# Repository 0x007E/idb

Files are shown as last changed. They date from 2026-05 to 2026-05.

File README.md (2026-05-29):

  

# `IDB` - Inverter Development Board

The `IDB` is a board with an [CD40106](#additional-information) or any other 6-channel inverter that meets the pin requirements. The board itself can be driven from `5` to `15V`. The board offers the possibility to invert signals from buttons, switches or any other logic board.

| Experience  | Level |
|:---|:---:|
| Soldering | ?% |

# Downloads

| Type | File | Description |
|:---:|:---:|:---|
| Schematic | [pdf](https://github.com/0x007E/idb/releases/latest/download/schematic.pdf) / [cadlab](https://cadlab.io/project/30124/main/files) | Schematic files |
| Board | [pdf](https://github.com/0x007E/idb/releases/latest/download/pcb.pdf) / [cadlab](https://cadlab.io/project/30124/main/files) | Board file |
| Drill | [pdf](https://github.com/0x007E/idb/releases/latest/download/drill.pdf) | Drill file |
| BoM | [xlsx](https://github.com/0x007E/idb/releases/latest/download/bom.xlsx) / [html](https://github.com/0x007E/idb/releases/latest/download/bom.html) | Bill of Material as Excel/interactive HTML |
| PCB | [zip](https://github.com/0x007E/idb/releases/latest/download/kicad.zip) / [tar](https://github.com/0x007E/idb/releases/latest/download/kicad.tar.gz) | KiCAD/Gerber/BoM/Drill files |
| Mechanical | [zip](https://github.com/0x007E/idb/releases/latest/download/freecad.zip) / [tar](https://github.com/0x007E/idb/releases/latest/download/freecad.tar.gz) | FreeCAD/Housing and PCB (STEP/STL) files |

# Hardware

The pcb is created with `KiCAD`. All files are built with `github actions` so that they are ready for a production environment.

## PCB

The circuit board is populated on both sides (Top, Bottom). The best way for soldering the `SMD` components is within a vapor phase soldering system and for the `THT` components with a standard soldering system.

### Top Layer

Top Layer

### Bottom Layer

Bottom Layer

# Additional Information

| Type | Link | Description |
|:---:|:---:|:---|
| CD40106 | [pdf](https://www.ti.com/lit/ds/symlink/cd40106b.pdf) | CD40106B CMOS Hex Schmitt-Trigger Inverters |

---

R. GAECHTER

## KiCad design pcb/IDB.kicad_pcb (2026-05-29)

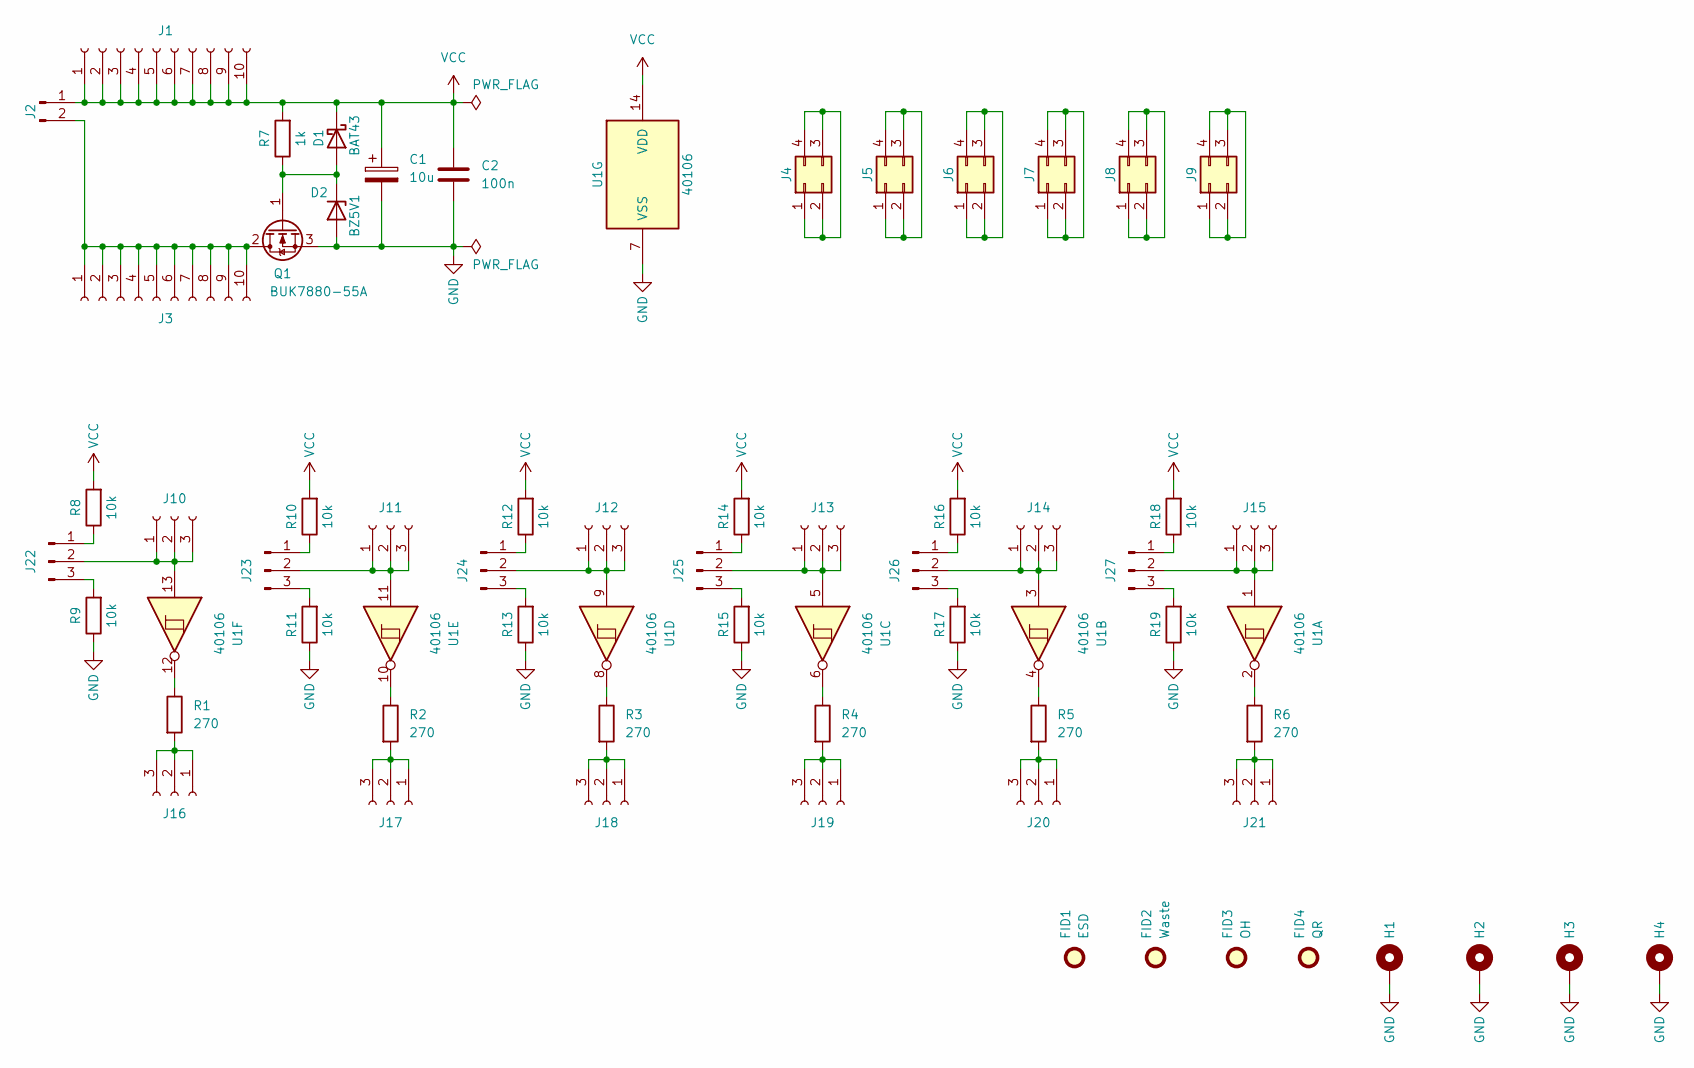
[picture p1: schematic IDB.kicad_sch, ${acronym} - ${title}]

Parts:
C1: 10u; CP_Radial_D6.3mm_P2.50mm
C2: 100n; C_1206_3216Metric
D1: BAT43; D_MiniMELF
D2: BZ5V1; D_MiniMELF
FID1: ESD; ESD-Logo_6.6x6mm_SilkScreen
FID2: Waste; WEEE-Logo_4.2x6mm_SilkScreen
FID3: OH; OSHW-Logo_5.7x6mm_SilkScreen
FID4: QR; QR_0x007e
H1, H2, H3, H4: MountingHole_Pad; MountingHole_3.2mm_M3_Pad
J1, J3: Conn_01x10_Socket; PinSocket_1x10_P2.54mm_Vertical; DigiKey 2057-RS1-10-G-ND
J2: Conn_01x02_Pin; PinHeader_1x02_P2.54mm_Vertical
J4, J5, J6, J7, J8, J9: Conn_02x02_Counter_Clockwise; PinSocket_2x02_P2.54mm_Vertical; DigiKey 2057-RS2-04-G-ND
J10, J11, J12, J13, J14, J15, J16, J17, J18, J19, J20, J21: Conn_01x03_Socket; PinSocket_1x03_P2.54mm_Vertical; DigiKey 2057-RS1-03-G-ND
J22, J23, J24, J25, J26, J27: Conn_01x03_Pin; PinHeader_1x03_P2.54mm_Vertical
Q1: BUK7880-55A; SOT-223-3_TabPin2
R1, R2, R3, R4, R5, R6: 270; R_1206_3216Metric
R7: 1k; R_1206_3216Metric
R8, R9, R10, R11, R12, R13, R14, R15, R16, R17, R18, R19: 10k; R_1206_3216Metric
U1: 40106; SOIC-14_3.9x8.7mm_P1.27mm; DigiKey 296-14081-1-ND

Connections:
GND: C1.2, C2.2, D2.2 (A), H1.1, H2.1, H3.1, H4.1, Q1.3 (S), R9.1, R11.1, R13.1, R15.1, R17.1, R19.1, U1.7 (VSS)
unnamed: D1.2 (A), D2.1 (K), Q1.1 (G), R7.1
unnamed: J2.2, J3.1, J3.2, J3.3, J3.4, J3.5, J3.6, J3.7, J3.8, J3.9, J3.10, Q1.2 (D)
unnamed: J4.1, J4.2, J4.3, J4.4
unnamed: J5.1, J5.2, J5.3, J5.4
unnamed: J6.1, J6.2, J6.3, J6.4
unnamed: J7.1, J7.2, J7.3, J7.4
unnamed: J8.1, J8.2, J8.3, J8.4
unnamed: J9.1, J9.2, J9.3, J9.4
unnamed: J10.1, J10.2, J10.3, J22.2, U1.13
unnamed: J11.1, J11.2, J11.3, J23.2, U1.11
unnamed: J12.1, J12.2, J12.3, J24.2, U1.9
unnamed: J13.1, J13.2, J13.3, J25.2, U1.5
unnamed: J14.1, J14.2, J14.3, J26.2, U1.3
unnamed: J15.1, J15.2, J15.3, J27.2, U1.1
unnamed: J16.1, J16.2, J16.3, R1.2
unnamed: J17.1, J17.2, J17.3, R2.2
unnamed: J18.1, J18.2, J18.3, R3.2
unnamed: J19.1, J19.2, J19.3, R4.2
unnamed: J20.1, J20.2, J20.3, R5.2
unnamed: J21.1, J21.2, J21.3, R6.2
unnamed: J22.1, R8.1
unnamed: J22.3, R9.2
unnamed: J23.1, R10.1
unnamed: J23.3, R11.2
unnamed: J24.1, R12.1
unnamed: J24.3, R13.2
unnamed: J25.1, R14.1
unnamed: J25.3, R15.2
unnamed: J26.1, R16.1
unnamed: J26.3, R17.2
unnamed: J27.1, R18.1
unnamed: J27.3, R19.2
unnamed: R1.1, U1.12
unnamed: R2.1, U1.10
unnamed: R3.1, U1.8
unnamed: R4.1, U1.6
unnamed: R5.1, U1.4
unnamed: R6.1, U1.2
VCC: C1.1, C2.1, D1.1 (K), J1.1, J1.2, J1.3, J1.4, J1.5, J1.6, J1.7, J1.8, J1.9, J1.10, J2.1, R7.2, R8.2, R10.2, R12.2, R14.2, R16.2, R18.2, U1.14 (VDD)

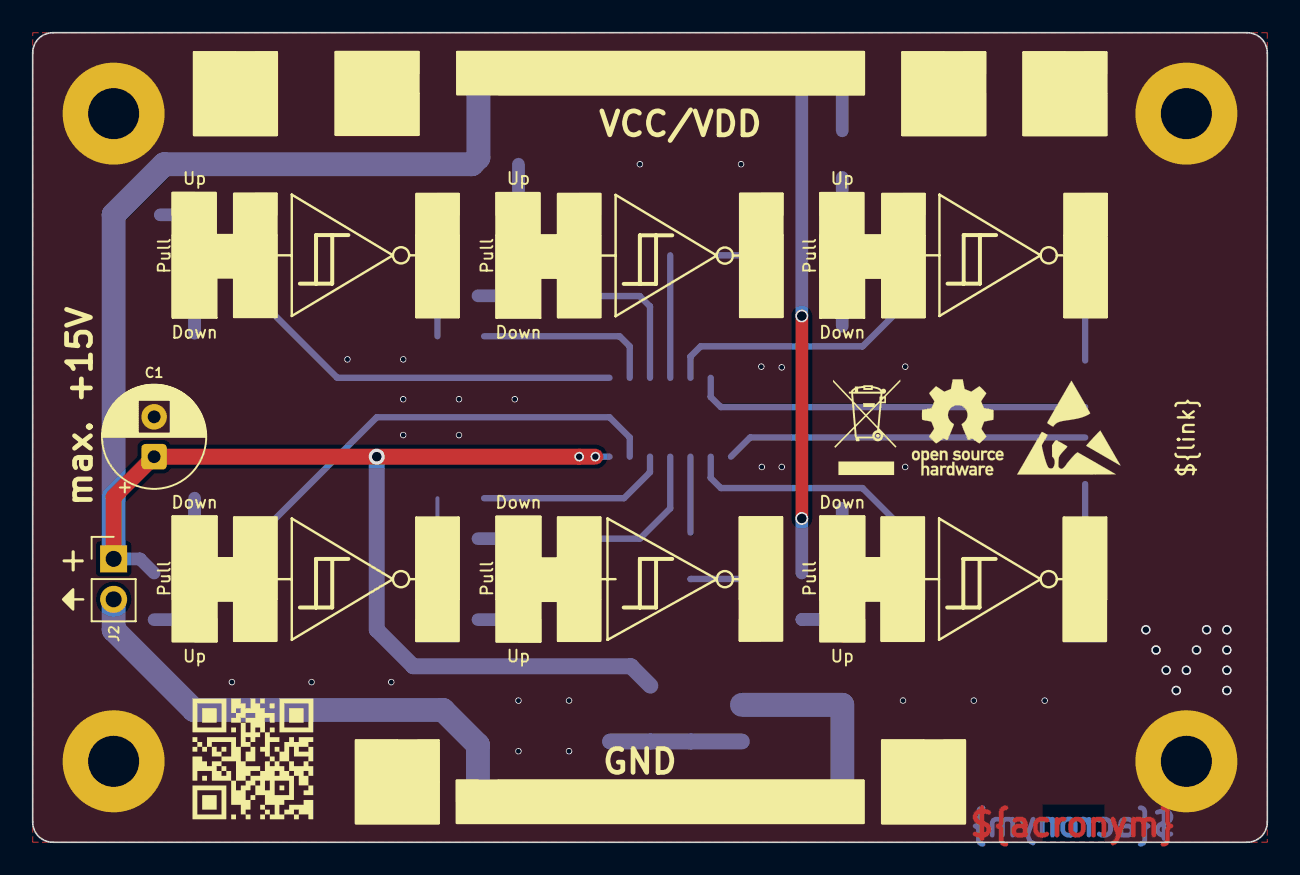
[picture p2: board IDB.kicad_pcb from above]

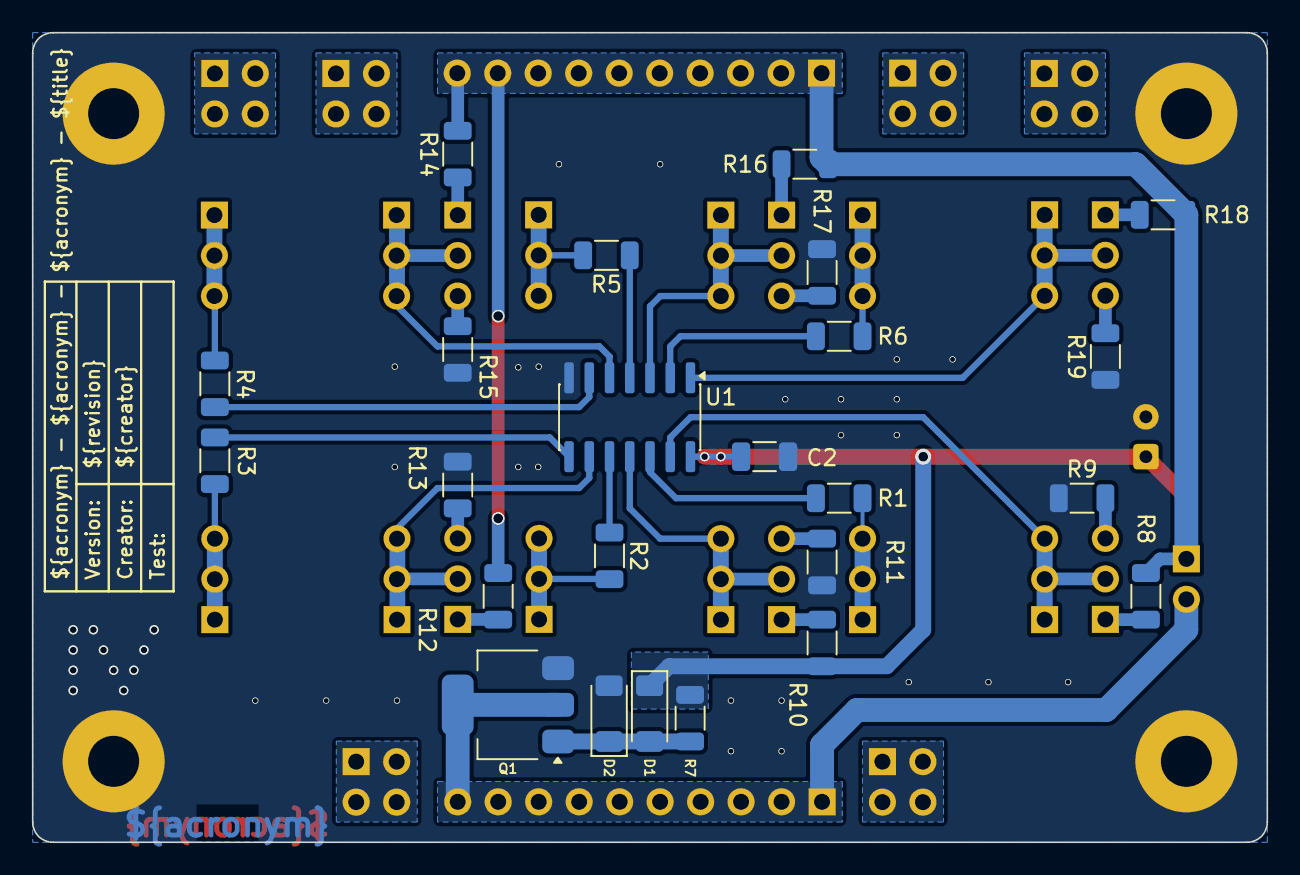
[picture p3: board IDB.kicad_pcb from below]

Board: 2 copper layers, 77.5 x 50.8 mm, 60 parts (24 on the bottom side), 40 nets.

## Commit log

2026-03-02 Add pcb layout
    [IDB.kicad_pcb, IDB.kicad_sch]
2026-03-23 Adapt edge cuts and dimensioning
    [IDB.kicad_pcb]
2026-05-09 Add reverse polarity protection
    [IDB.kicad_pcb, IDB.kicad_sch]
2026-05-09 Remove isolated copper filter
2026-05-11 Optimize fabrication layer
    [IDB.kicad_pcb]
2026-05-28 Add missing inversion at silkscreen
    [IDB.kicad_pcb]
2026-05-29 Add push/pull possibility for inputs
    [IDB.kicad_pcb, IDB.kicad_sch]
2026-05-29 Update to KiCAD 9
    [IDB.kicad_pcb, IDB.kicad_sch]
2026-05-29 Rename/Add/Remove bom fields
    [IDB.kicad_pcb, IDB.kicad_sch]
2026-05-29 Optimize silkscreen
    [IDB.kicad_pcb]

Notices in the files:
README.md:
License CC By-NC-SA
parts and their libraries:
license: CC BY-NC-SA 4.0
